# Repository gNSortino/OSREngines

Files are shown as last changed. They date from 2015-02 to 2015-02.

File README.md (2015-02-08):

# OSREngines
Open Source Rocket Engines

## What is this??
This Git Repository contains CAD design files for open source liquid fueled rocket engines that I like to build. More information regarding the project can be found on the FUBAR labs wiki [here](http://wiki.fubarlabs.org/fubarwiki/Small-Liquid-Fueled-Rocket-Engines.ashx).

## What can I do with this??
You can do whatever you like with these files provided it complies with the Creative Commons Attribution-ShareAlike 4.0 International License. For example, if you are interested in building your own engine it may be helpful to view this to see what others have built first so that you aren't starting 100% from scratch. Or you may wish to make or suggest improvements to these models.

## Repository Structure??
This repository has the following structure:
* Igniters
* Injectors
* Engines

Every sub-folder in the above directories is a self-contained unit containing stl files, design files/analysis, and other supporting materials. The contents of each folder may vary so check each one individually for details. 

In many cases components are meant to mate with each other. For example, an engine may be designed to mate with a specific injector and igniter. In these instances pointers to the additional components are referenced. So if you are interested in testing an engine that goes with a specific injector you could either download the corresponding injector or modify the underlying CAD file to mate with a diffierent injector. All design files contain details of port-fitting, etc... so it should be relatively straightforward to connect these components.

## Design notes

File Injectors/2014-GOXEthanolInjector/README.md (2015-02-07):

# 2014 - GOX Ethanol Injector

## Description
My first attempt at 3D printing an injecotr. The injecor has 3 inputs:
1. Fuel (Ethanol)
2. Oxidizer (GOX)
3. Flame Tube from spark igniter

The injetor is meant to mate with:
* [This engine](../../Engines/2014-GOXEthanolRegenEngine)
* [This igniter](../../Igniters/2014-GOXEthanolTest)

## Build Instructions
This is an STL only. Unfortunately, I do not have the underlying files

## Resources
* A copy of the model can be found on [Shapeways](http://shpws.me/EGmQ)
* Information about the igniter and testing can be found on the FUBAR labs Wiki [here](http://wiki.fubarlabs.org/fubarwiki/GOX-Ethanol-Igniter-v3-3D-Printed-2014.ashx)
* [Excel Design Spreadsheet](../../Engines/2014-GOXEthanolRegenEngine/2014-GOXEthanolRegenEngine.Design.xlsx) *(Contained w/in Git)*
* [RPA Design File](../../Engines/2014-GOXEthanolRegenEngine/2014-GOXEthanolRegenEngine.RPA.cfg) *(Contained w/in Git)*

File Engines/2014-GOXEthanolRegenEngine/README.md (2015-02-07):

# 2014 - GOX Ethanol Regen Engine 

## Description
My first attempt at producing a working regenerative 3D printed rocket engine. The engine is designed to run off GOX/Ethanol at 150psia and generate 50lbf of thrust. Unfortunately, producing this much thrust proved difficult as I could not generate enough GOX mass flow to achieve this thrust level. Also, the regenerative channels did not print correctly (this is a challenge with SLS printing), however, the engine did successfully fired. I learned a lot from the experience and plan to use this experience to improve for future designs.

The engine is meant to mate with:
* [This injector](../../Injectors/2014-GOXEthanolInjector)
* [This igniter](../../Igniters/2014-GOXEthanolTest)

## Build Instructions
This is an STL only. Unfortunately, I do not have the underlying files

## Resources
* A copy of the model can be found on [Shapeways](http://shpws.me/EGlh)
* Information about the igniter and testing can be found on the FUBAR labs Wiki [here](http://wiki.fubarlabs.org/fubarwiki/3D-Printed-Engine.ashx)
* [Excel Design Spreadsheet](../../Engines/2014-GOXEthanolRegenEngine/2014-GOXEthanolRegenEngine.Design.xlsx) *(Contained w/in Git)*
* [RPA Design File](../../Engines/2014-GOXEthanolRegenEngine/2014-GOXEthanolRegenEngine.RPA.cfg) *(Contained w/in Git)*

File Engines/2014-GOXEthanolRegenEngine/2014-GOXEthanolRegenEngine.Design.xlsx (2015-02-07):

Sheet: VesselCharacteristics
 | Characteristics of a Vehicle in Motion |  |  |  |  |  |  |  |  |  |  |  |  |  |  |  |  |  |  |  |  |  | Chamber & Nozzle Measurements For Graph
 |  |  |  |  |  |  |  | 7.911e-05 | 5 | 0.005 |  |  |  |  |  |  |  |  |  | Propellent Mass Budget Analysis for Change in Velocity Increment |  |  | x | y-top | y-bottom | y-top-outer | y-bottom-outer | y-tube-top-upper | y-tube-top-lower | y-tube-bottom-upper | y-tube-bottom-lower
Instructions: This advanced equation takes a number of bipropellant liquid engine inputs and models a variety of outputs including: velocity, altitude, acceleration, nozzle dimensions, and heat-transfer. All input data should be filled in the yellow boxes. Anything in grey will be calculated automatically and green values are key outputs also calculated automatically. The charts will also update automatically. Note that thermal conductivity calculations do not consider carbon deposits or nucleate boiling |  |  |  |  |  |  |  |  |  |  |  |  |  |  |  |  |  |  |  | Velocity Increase (m/sec) | Propellent Mass (kg) | Change in Propellent Mass (kg) | 0 | 1.57775 | 0.159 | 1.73630 | 0.060 | 1.62696 | 1.63788 | 0.10934 | 0.0984251967
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

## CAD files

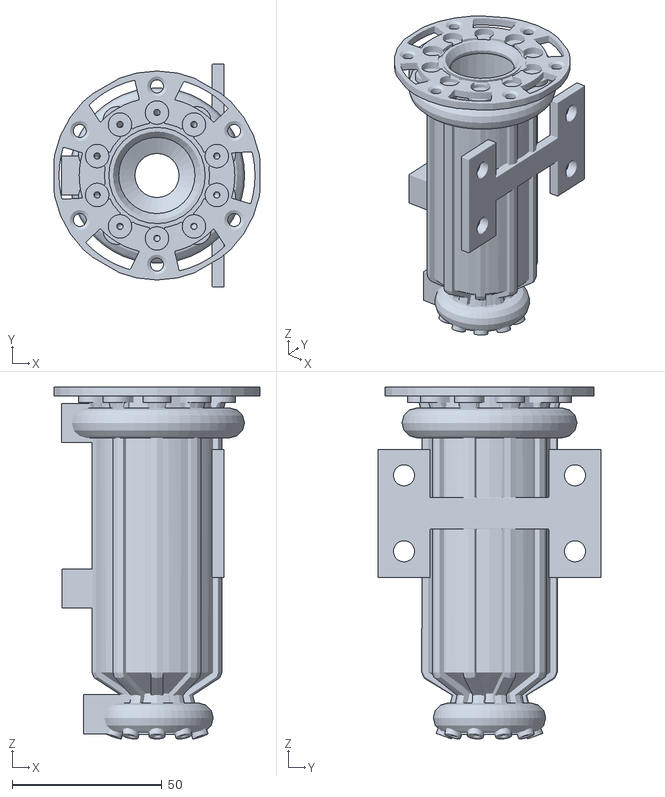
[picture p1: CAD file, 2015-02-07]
Engines/2014-GOXEthanolRegenEngine/2014-GOXEthanolRegenEngine.stl
68.9 x 74.6 x 117.7

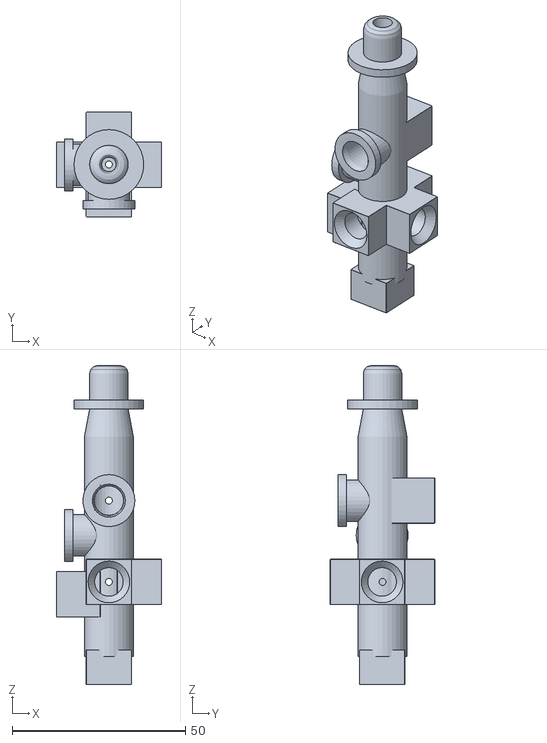
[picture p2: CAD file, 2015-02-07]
Igniters/2014-GOXEthanolTest/2014-GOXEthanolTestIgniter.stl
30.3 x 30.1 x 92.0

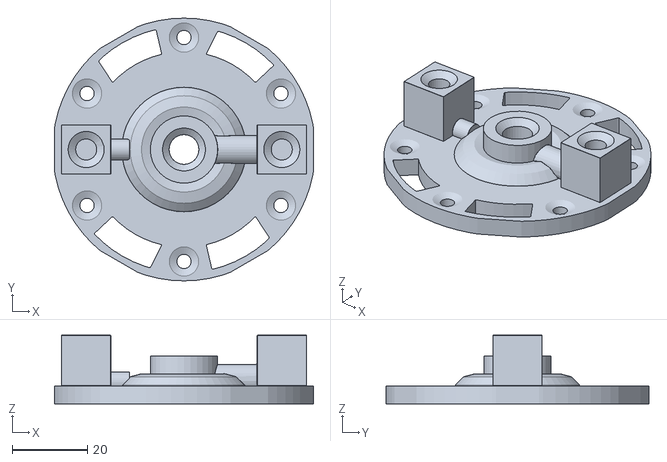
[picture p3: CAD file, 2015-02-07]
Injectors/2014-GOXEthanolInjector/2014-GOXEthanolInjector.stl
68.9 x 69.9 x 18.3

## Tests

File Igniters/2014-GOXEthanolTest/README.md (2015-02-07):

# 2014 - GOX Ethanol Test Igniter

## Description
My first attempt at 3D printing a spark igniter. The igniter is designed to run off GOX/Ethanol at 100psia and produce 2.5 lbf of thrust. The igniter has many ports to in order to find the optimal orifice designs and work out some issues with my earlier traditionally machined igniters.

Since this igniter is mainly meant for my own testing purposes it is probably not very useful in general projects as I will be producing more refined versions of this design based on the lessons I've learned from testing this one. However, feel free to use it in your projects.

## Build Instructions
This is an STL only. Unfortunately, I do not have the underlying files

## Resources
* A copy of the model can be found on [Shapeways](http://shpws.me/EGdb)
* Information about the igniter and testing can be found on the FUBAR labs Wiki [here](http://wiki.fubarlabs.org/fubarwiki/GOX-Ethanol-Igniter-v3-3D-Printed-2014.ashx)
* Excel Design Spreadsheet (contained w/in git)
* RPA Design File (contained w/in git)

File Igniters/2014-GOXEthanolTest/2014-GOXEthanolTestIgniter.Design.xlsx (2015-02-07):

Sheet: VesselCharacteristics
 | GOX/Ethanol Igniter v3 Properties |  |  |  |  |  |  |  |  |  |  | Chamber & Nozzle Measurements For Graph |  |  |  |  |  |  |  |  | output psi | gas choked | gas non-choked | gas is choked? | gas (cumulative) | liquid | total mass flow | O/F Ratio | Design Gas Flow | Design Liquid Flow | Design total mass flow | Design O/F Ratio
 |  |  |  |  |  |  |  |  |  |  |  | x | y-top | y-bottom | y-top-outer | y-bottom-outer | y-tube-top-upper | y-tube-top-lower | y-tube-bottom-upper | y-tube-bottom-lower | 15 | 0.003152430326 | 0.003436478672 | TRUE | 0.003152430326 | 0.003298283701 | 0.006450714027 | 0.9557790087 | 0.003152430 | 0.002424946 | 0.005577377 | 1.3
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

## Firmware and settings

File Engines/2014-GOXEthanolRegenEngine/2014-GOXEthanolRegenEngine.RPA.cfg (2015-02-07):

version = 1.2;
name = "GOX / Ethanol Regen Engine";
info = "2013-01-21 - Design Started on\n2013-03-24 - updated to 50lbf and tried to add film cooling\n2013-03-29 - fine tuning of design\n2013-06-09 - Updates to do Heat Transfer Comparison.\n2013-07-17 - updated with film cooling (closer to a final draft)\n2013-11-04 - fine tune properties";
generalOptions : 
{
  multiphase = true;
  ions = true;
  flowSeparation = true;
};
combustionChamberConditions : 
{
  pressure : 
  {
    value = 150.0;
    unit = "psi";
  };
};
nozzleFlow : 
{
  calculateNozzleFlow = true;
  nozzleInletConditions : 
  {
    contractionAreaRatio = 6.0;
  };
  nozzleExitConditions : 
  {
    pressure : 
    {
      value = 14.7;
      unit = "psi";
    };
  };
  efficiencies : 
  {
    nozzleHalfAngle = 15.0;
  };
  ambientConditions : 
  {
    pressure : 
    {
      value = 14.7;
      unit = "psi";
    };
    calculateDeliveredPerformance = true;
  };
  nozzleStations = ( );
};
propellant : 
{
  components : 
  {
    ratio : 
    {
      value = 1.0;
      unit = "O/F";
    };
    oxidizer = ( 
      {
        name = "O2";
        massFraction = 1.0;
        T : 
        {
          value = 280.0;
          unit = "K";
        };
        p : 
        {
          value = 200.0;
          unit = "psi";
        };
      } );
    fuel = ( 
      {
        name = "C2H5OH(L),90%";
        massFraction = 1.0;
        T : 
        {
          value = 350.0;
          unit = "K";
        };
        p : 
        {
          value = 500.0;
          unit = "psi";
        };
      } );
  };
};
engineSize : 
{
  throatDiameter : 
  {
    value = 0.57938;
    unit = "in";
  };
  chambersNo = 1;
  chamberGeometry : 
  {
    length : 
    {
      value = 4.0;
      unit = "in";
    };
    characteristicLength = false;
    contractionAngle = 30.0;
    R1_to_Rt_ratio = 1.5;
    Rn_to_Rt_ratio = 0.382;
    R2_to_R2max_ratio = 0.5;
  };
};
chamberCooling : 
{
  heatTransfer : 
  {
    relationsType = "Bartz";
    applyBLC = false;
    numberOfStations = 50;
    radiationHeatTransfer : 
    {
      hotSideWallSurfaceEmissivity = 0.8;
    };
    wallLayerHeight = 0.05;
  };
  chamberCoolingSections = ( 
    {
      channelJacketDesign : 
      {
        location : 
        {
          value = 0.0;
          unit = "mm";
        };
        length : 
        {
          value = 0.0;
          unit = "m";
        };
        wallThickness : 
        {
          value = 1.25;
          unit = "mm";
        };
        id = "1";
        wallConductivity : 
        {
          value = 100.0;
          unit = "W/(m K)";
        };
        coolant = ( 
          {
            name = "C2H5OH(L)";
            massFraction = 0.9;
            T : 
            {
              value = 280.0;
              unit = "K";
            };
            p : 
            {
              value = 500.0;
              unit = "psi";
            };
          }, 
          {
            name = "H2O(L)";
            massFraction = 0.1;
            T : 
            {
              value = 280.0;
              unit = "K";
            };
            p : 
            {
              value = 500.0;
              unit = "psi";
            };
          } );
        flowrate = 0.5;
        oppositeFlow = true;
        height1 : 
        {
          value = 0.708;
          unit = "mm";
        };
        height2 : 
        {
          value = 0.708;
          unit = "mm";
        };
        gamma : 
        {
          value = 0.0;
          unit = "degrees";
        };
        a1 : 
        {
          value = 0.708;
          unit = "mm";
        };
        a2 : 
        {
          value = 0.708;
          unit = "mm";
        };
        n = 10;
      };
    } );
  filmSlots = ( 
    {
      location : 
      {
        value = 0.0;
        unit = "mm";
      };
      coolant = ( 
        {
          name = "C2H5OH(L)";
          massFraction = 0.9;
          T : 
          {
            value = 350.0;
            unit = "K";
          };
          p : 
          {
            value = 500.0;
            unit = "psi";
          };
        }, 
        {
          name = "H2O(L)";
          massFraction = 0.1;
          T : 
          {
            value = 350.0;
            unit = "K";
          };
          p : 
          {
            value = 500.0;
            unit = "psi";
          };
        } );
      flowrate = 0.0;
    } );
};
propelantFeedSystem : 
{
  estimateDryMass = false;
};

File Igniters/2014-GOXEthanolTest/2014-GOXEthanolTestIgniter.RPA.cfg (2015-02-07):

version = 1.2;
name = "GOX / Ethanol Igniter v3";
info = "2014-09-26 - inital version\n";
generalOptions : 
{
  multiphase = true;
  ions = true;
  flowSeparation = true;
};
combustionChamberConditions : 
{
  pressure : 
  {
    value = 100.0;
    unit = "psi";
  };
};
nozzleFlow : 
{
  calculateNozzleFlow = true;
  nozzleInletConditions : 
  {
    contractionAreaRatio = 5.84;
  };
  nozzleExitConditions : 
  {
    pressure : 
    {
      value = 14.696;
      unit = "psi";
    };
  };
  efficiencies : 
  {
    nozzleHalfAngle = 5.0;
  };
  ambientConditions : 
  {
    pressure : 
    {
      value = 14.7;
      unit = "psi";
    };
    calculateDeliveredPerformance = true;
  };
  nozzleStations = ( );
};
propellant : 
{
  components : 
  {
    ratio : 
    {
      value = 1.3;
      unit = "O/F";
    };
    oxidizer = ( 
      {
        name = "O2";
        massFraction = 1.0;
        T : 
        {
          value = 280.0;
          unit = "K";
        };
        p : 
        {
          value = 200.0;
          unit = "psi";
        };
      } );
    fuel = ( 
      {
        name = "C2H5OH(L),90%";
        massFraction = 1.0;
        T : 
        {
          value = 280.0;
          unit = "K";
        };
        p : 
        {
          value = 500.0;
          unit = "psi";
        };
      } );
  };
};
engineSize : 
{
  throatDiameter : 
  {
    value = 0.16451;
    unit = "in";
  };
  chambersNo = 1;
  chamberGeometry : 
  {
    length : 
    {
      value = 2.5;
      unit = "in";
    };
    characteristicLength = false;
    contractionAngle = 15.0;
    R1_to_Rt_ratio = 1.5;
    Rn_to_Rt_ratio = 0.382;
    R2_to_R2max_ratio = 0.5;
  };
};
propelantFeedSystem : 
{
  estimateDryMass = false;
};

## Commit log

2015-02-07 uploaded 2014-GOX Ethanol Test Igniter
    [2014-GOXEthanolTestIgniter.Design.xlsx, 2014-GOXEthanolTestIgniter.RPA.cfg, 2014-GOXEthanolTestIgniter.stl]
2015-02-07 2014 Injector, Engine, Igniter Updates
    [2014-GOXEthanolInjector.stl, 2014-GOXEthanolRegenEngine.Design.xlsx, 2014-GOXEthanolRegenEngine.RPA.cfg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]
